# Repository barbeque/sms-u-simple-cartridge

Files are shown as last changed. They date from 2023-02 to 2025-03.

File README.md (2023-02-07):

# SMS-U Simple
A PCB for Sega Master System games. It's "simple" because it does not include any mapper (page switching, save RAM) logic, which means it only supports most Sega games up to 48K.

Note that this will not work on a Mark III/Japanese Master System; that system's pinout and cartridge shape is totally different.

## Current Status
In development

## Tested With
 * _Snail Maze_ ROM hack

## Bill of Materials
 * PCB
 * (E)EPROM containing your software - 27c64, up to 27c256. 27c512 may work, but only the lower half of the ROM will be accessible.
 * 0.1uF through-hole bypass capacitor

## Assembly Instructions
 1. Submit the gerbers from the Releases page to a PCB fabricator. Suggested settings: gold fingers (ENIG or ideally hard gold,) 45 degree bevel.
 2. If you didn't get edge connector beveling (45-degree fingers) from your PCB fabricator, it may make sense to do the beveling yourself with a sanding block.
 3. Place components onto board. If you are socketing your ROM, the socket may add too much additional height and keep a stock case from fitting.
 4. If you are using a 27c64 for your EPROM (rare,) cut the A14 jumper in the top right of the board and connect the +5V jumper instead. Verify with a multimeter.

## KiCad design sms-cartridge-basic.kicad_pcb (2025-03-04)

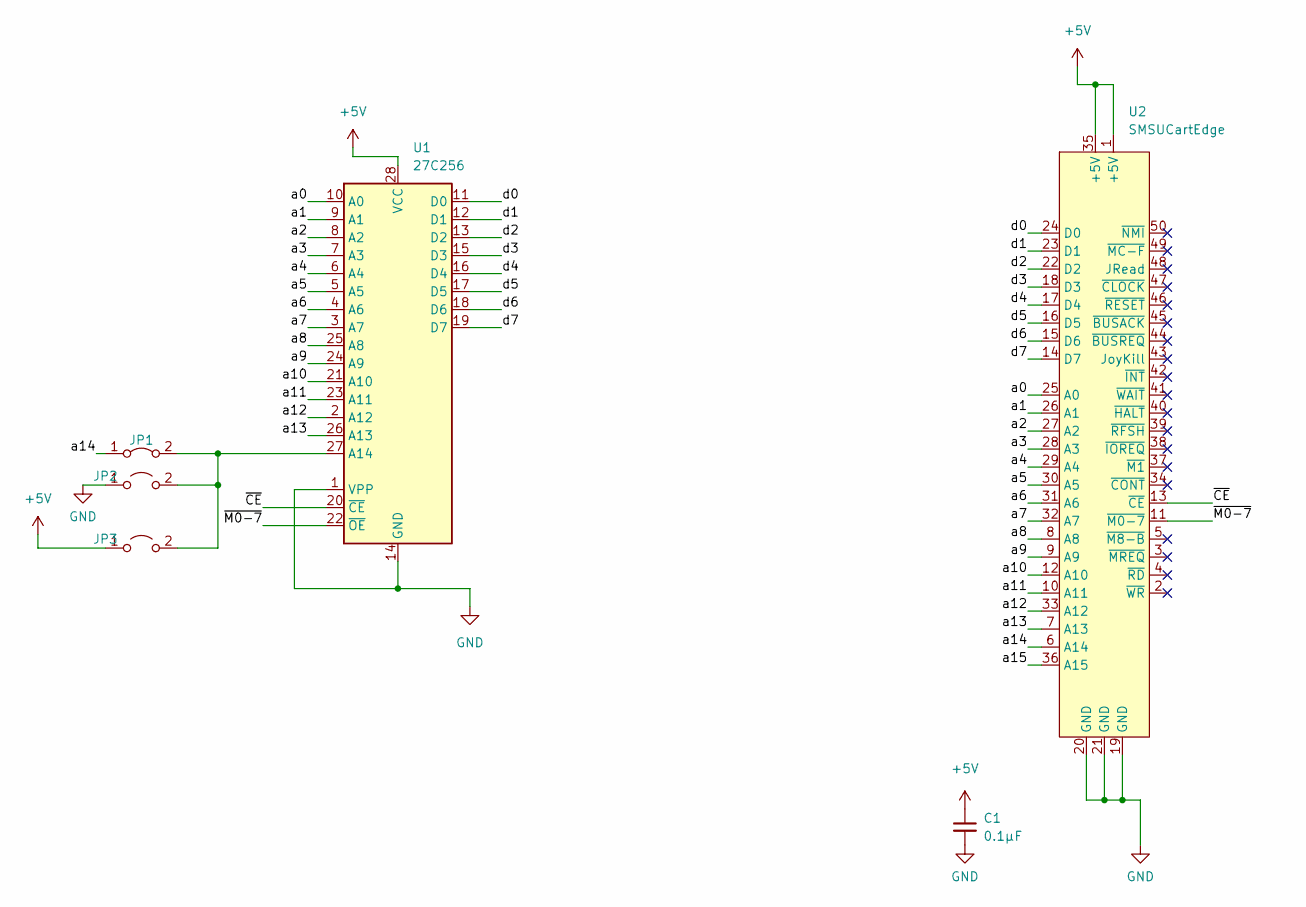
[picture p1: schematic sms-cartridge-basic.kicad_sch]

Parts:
C1: 0.1µF; C_Disc_D3.8mm_W2.6mm_P2.50mm
JP1: Jumper_2_Bridged; SolderJumper-2_P1.3mm_Bridged_RoundedPad1.0x1.5mm
JP2, JP3: Jumper_2_Open; SolderJumper-2_P1.3mm_Open_RoundedPad1.0x1.5mm
U1: 27C256; DIP-28_W15.24mm
U2: SMSUCartEdge; SMS_Cartridge

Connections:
+5V: C1.1, JP3.1 (A), U1.28 (VCC), U2.1 (+5V), U2.35 (+5V)
/a0: U1.10 (A0), U2.25 (A0)
/a1: U1.9 (A1), U2.26 (A1)
/a2: U1.8 (A2), U2.27 (A2)
/a3: U1.7 (A3), U2.28 (A3)
/a4: U1.6 (A4), U2.29 (A4)
/a5: U1.5 (A5), U2.30 (A5)
/a6: U1.4 (A6), U2.31 (A6)
/a7: U1.3 (A7), U2.32 (A7)
/a8: U1.25 (A8), U2.8 (A8)
/a9: U1.24 (A9), U2.9 (A9)
/a10: U1.21 (A10), U2.12 (A10)
/a11: U1.23 (A11), U2.10 (A11)
/a12: U1.2 (A12), U2.33 (A12)
/a13: U1.26 (A13), U2.7 (A13)
/a14: JP1.1 (A), U2.6 (A14)
/a15: U2.36 (A15)
/d0: U1.11 (D0), U2.24 (D0)
/d1: U1.12 (D1), U2.23 (D1)
/d2: U1.13 (D2), U2.22 (D2)
/d3: U1.15 (D3), U2.18 (D3)
/d4: U1.16 (D4), U2.17 (D4)
/d5: U1.17 (D5), U2.16 (D5)
/d6: U1.18 (D6), U2.15 (D6)
/d7: U1.19 (D7), U2.14 (D7)
/~CE: U1.20 (~CE), U2.13 (~CE)
/~M0-7: U1.22 (~OE), U2.11 (~M0-7)
GND: C1.2, JP2.1 (A), U1.1 (VPP), U1.14 (GND), U2.19 (GND), U2.20 (GND), U2.21 (GND)
unnamed: JP1.2 (B), JP2.2 (B), JP3.2 (B), U1.27 (A14)

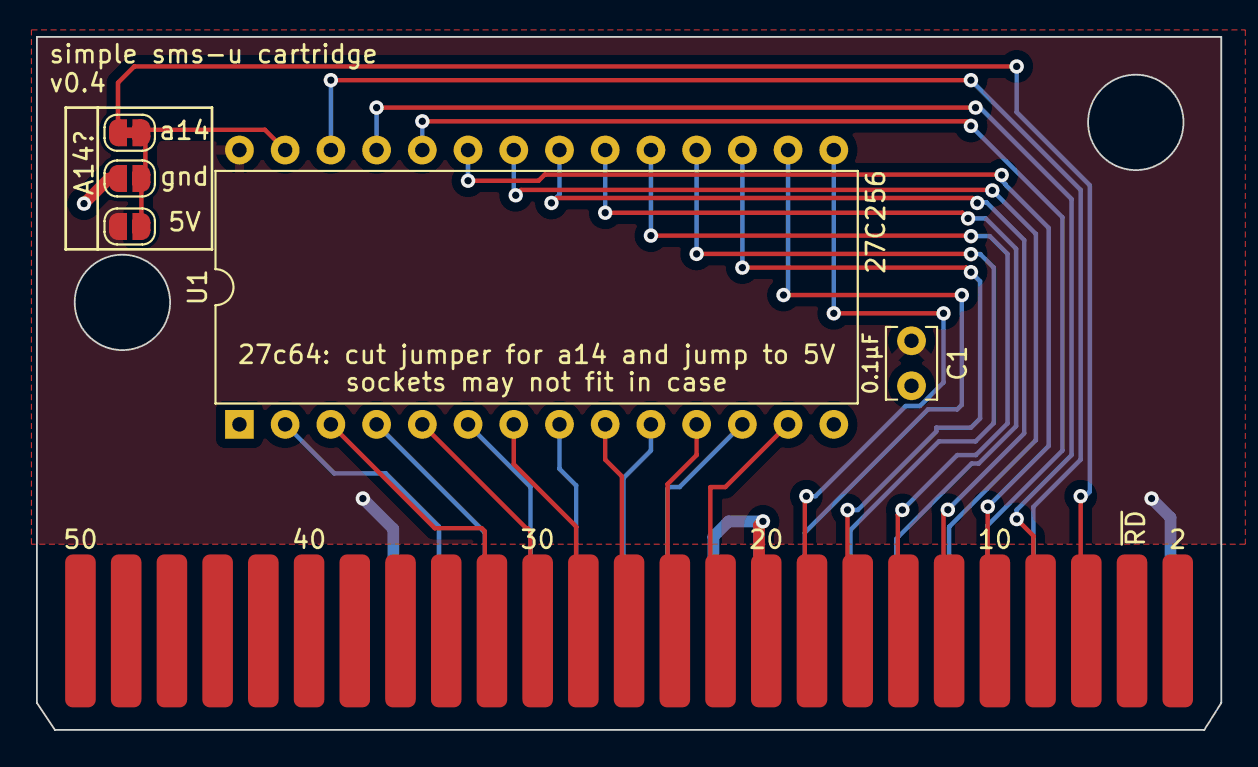
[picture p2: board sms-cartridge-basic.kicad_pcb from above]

Board: 2 copper layers, 65.8 x 38.5 mm, 6 parts (0 on the bottom side), 28 nets.

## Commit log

2023-01-05 Basic outline
    [sms-cartridge-basic.kicad_pcb, sms-cartridge-basic.kicad_sch]
2023-01-05 Edge connector symbol, basic schematic
    [sms-cartridge-basic.kicad_pcb, sms-cartridge-basic.kicad_sch]
2023-01-20 Wider (0.8mm measurement error), wider teeth
    [sms-cartridge-basic.kicad_pcb]
2023-01-20 Bodge to M0-7
    [sms-cartridge-basic.kicad_pcb, sms-cartridge-basic.kicad_sch]
2023-01-31 Prepare for v3
    [sms-cartridge-basic.kicad_pcb]
2023-02-07 27c64 support
    [sms-cartridge-basic.kicad_pcb, sms-cartridge-basic.kicad_sch]
2023-02-07 Update schematic
    [sms-cartridge-basic.kicad_sch]
2025-03-04 Upgrade to KiCad 9
    [sms-cartridge-basic.kicad_pcb, sms-cartridge-basic.kicad_sch]
